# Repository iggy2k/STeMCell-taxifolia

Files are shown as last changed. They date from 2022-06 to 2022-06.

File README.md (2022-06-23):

# STeMCell-taxifolia
 STeMCell 1.0.0 but with STM32F401RCT6. Same functionality (almost), but for 5$ less per board.

Original STeMCell made by https://github.com/megamind4089

To use: https://megamind4089.github.io/STeMCell/

Changed nothing except the STM, positioning and silkscreens (still no on-board protections).

Haven't purchased yet, but it should work.

<p align="center">
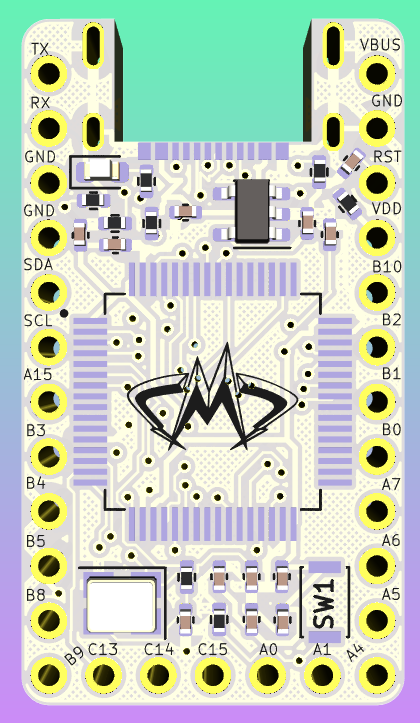
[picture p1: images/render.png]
  
</p>

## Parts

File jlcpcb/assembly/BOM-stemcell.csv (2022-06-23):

Comment | Designator | Footprint | LCSC
100n | C12,C4,C5,C6,C7,C8 | C_0402_1005Metric | C1525
10u | C1 | C_0402_1005Metric | C15525
20p | C10,C11 | C_0402_1005Metric | C1554
4.7u | C2,C3,C9 | C_0402_1005Metric | C23733
220 | R1 | R_0402_1005Metric | C25091
10k | R6,R7,R8 | R_0402_1005Metric | C25744
2k2 | R4 | R_0402_1005Metric | C25879
4.7k | R5 | R_0402_1005Metric | C25900
5k1 | R2,R3 | R_0402_1005Metric | C25905
USB C Connector | J1 | USB-C-C168688 | C2681552
HSE1 8Mhz 12pF | Y1 | Crystal_SMD_3225-4Pin_3.2x2.5mm | C2682775
Boot0 | SW1 | SW_SPST_CK_KXT3 | C319433
LED | D1 | LED_0603_1608Metric | C72041
STM32F401RCTx | U1 | QFP50P1200X1200X160-64N | C74524
XC6220B331MR | U2 | SOT-23-5 | C86534

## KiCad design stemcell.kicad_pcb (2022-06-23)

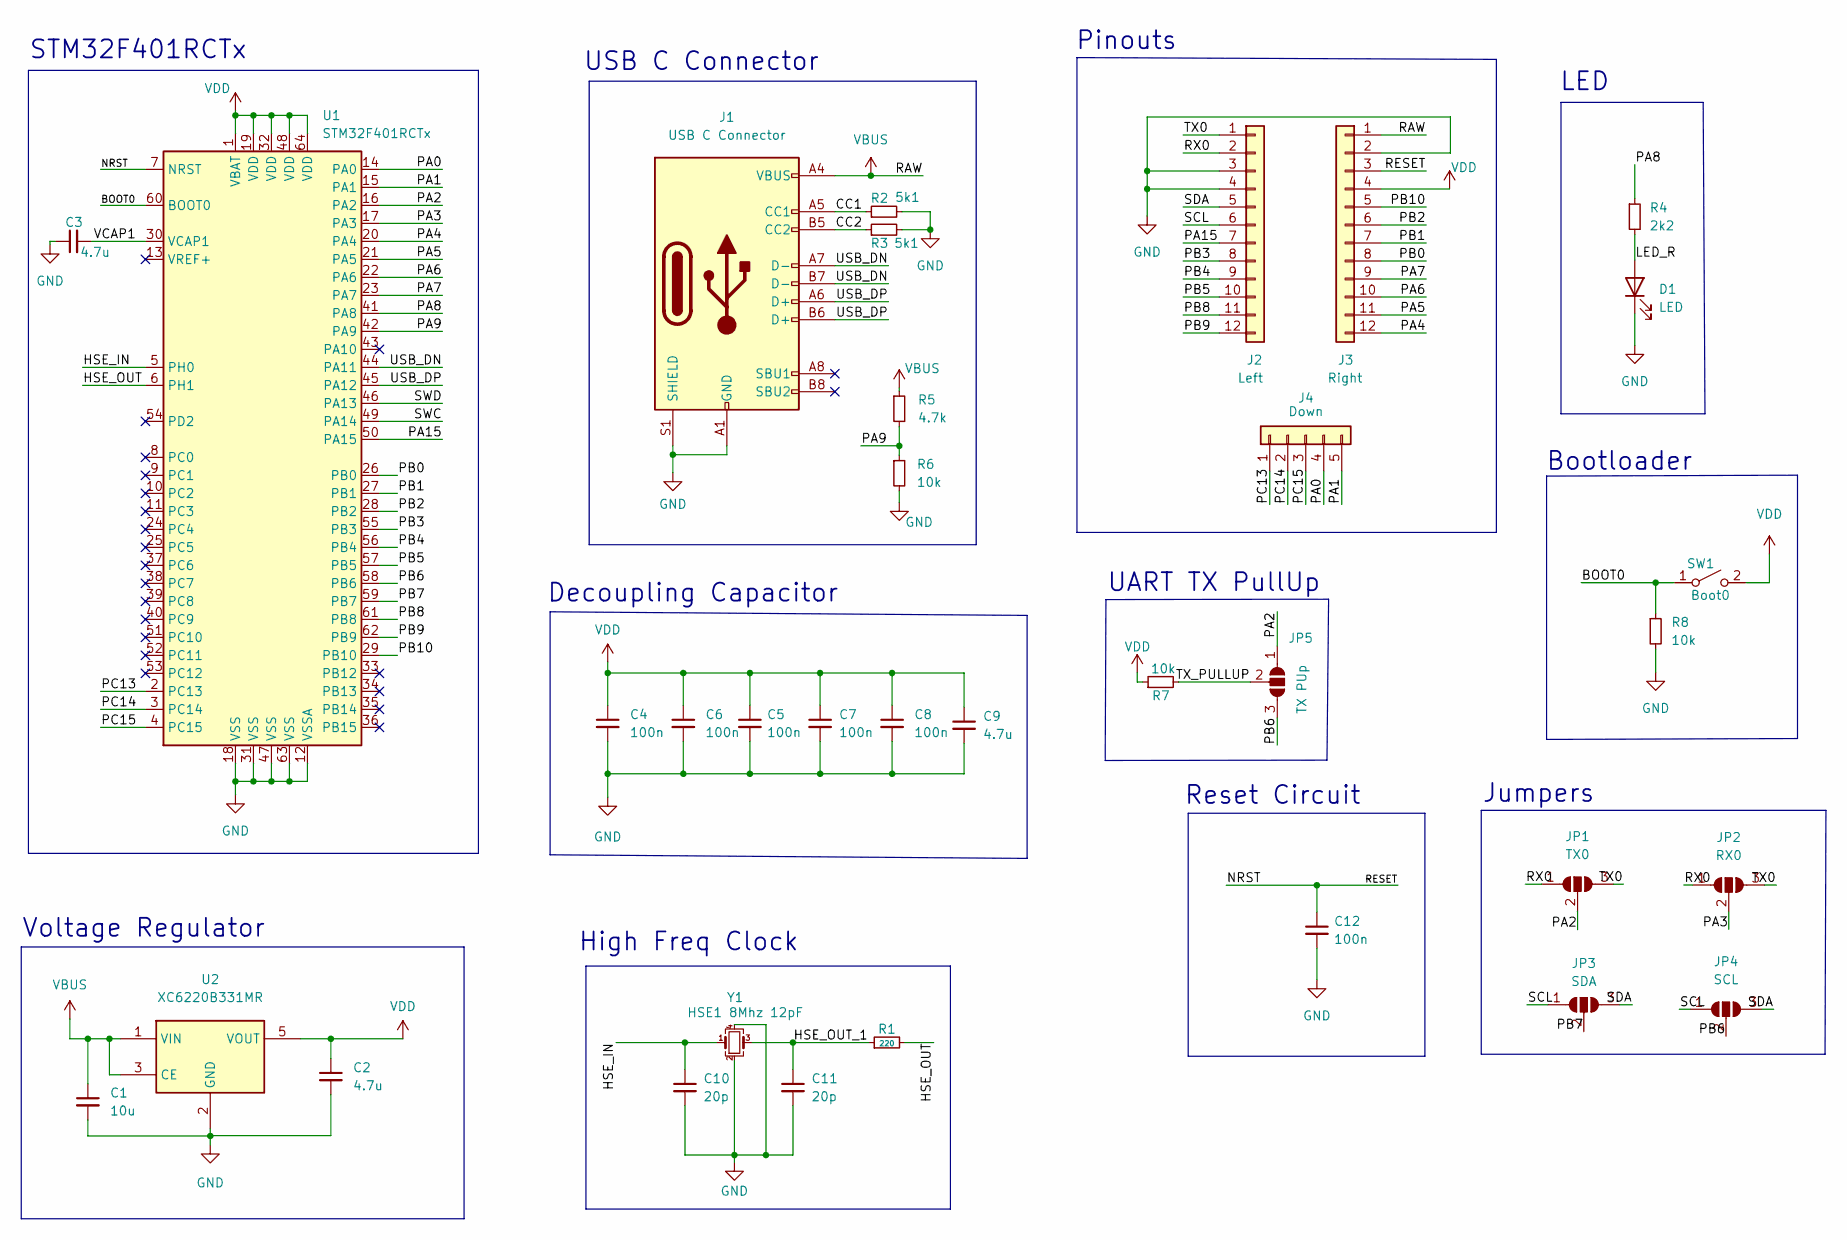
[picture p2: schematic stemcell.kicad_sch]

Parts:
C1: 10u; C_0402_1005Metric
C2, C3, C9: 4.7u; C_0402_1005Metric
C4, C5, C6, C7, C8, C12: 100n; C_0402_1005Metric
C10, C11: 20p; C_0402_1005Metric
D1: LED; LED_0603_1608Metric
J1: USB C Connector; USB-C-C168688
J2: Left; Pins_x12
J3: Right; Pins_x12
J4: Down; Pins_x05_Castellated
JP1: TX0; SOLDER_JUMPER_3
JP2: RX0; SOLDER_JUMPER_3
JP3: SDA; SOLDER_JUMPER_3
JP4: SCL; SOLDER_JUMPER_3
JP5: TX PUp; SOLDER_JUMPER_3
R1: 220; R_0402_1005Metric
R2, R3: 5k1; R_0402_1005Metric
R4: 2k2; R_0402_1005Metric
R5: 4.7k; R_0402_1005Metric
R6, R7, R8: 10k; R_0402_1005Metric
SW1: Boot0; SW_SPST_CK_KXT3
U1: STM32F401RCTx; QFP50P1200X1200X160-64N
U2: XC6220B331MR; SOT-23-5
Y1: HSE1 8Mhz 12pF; Crystal_SMD_3225-4Pin_3.2x2.5mm

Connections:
/BOOT0: R8.1, SW1.1 (A), U1.60 (BOOT0)
/CC1: J1.A5 (CC1), R2.1
/CC2: J1.B5 (CC2), R3.1
/HSE_IN: C10.1, U1.5 (PH0), Y1.1
/HSE_OUT: R1.2, U1.6 (PH1)
/HSE_OUT_1: C11.1, R1.1, Y1.3
/LED_R: D1.2 (A), R4.2
/NRST: C12.1, J3.3, U1.7 (NRST)
/PA0: J4.4, U1.14 (PA0)
/PA1: J4.5, U1.15 (PA1)
/PA2: JP1.2 (C), JP5.1 (A), U1.16 (PA2)
/PA3: JP2.2 (C), U1.17 (PA3)
/PA4: J3.12, U1.20 (PA4)
/PA5: J3.11, U1.21 (PA5)
/PA6: J3.10, U1.22 (PA6)
/PA7: J3.9, U1.23 (PA7)
/PA8: R4.1, U1.41 (PA8)
/PA9: R5.2, R6.1, U1.42 (PA9)
/PA15: J2.7, U1.50 (PA15)
/PB0: J3.8, U1.26 (PB0)
/PB1: J3.7, U1.27 (PB1)
/PB2: J3.6, U1.28 (PB2)
/PB3: J2.8, U1.55 (PB3)
/PB4: J2.9, U1.56 (PB4)
/PB5: J2.10, U1.57 (PB5)
/PB6: JP4.2 (C), JP5.3 (B), U1.58 (PB6)
/PB7: JP3.2 (C), U1.59 (PB7)
/PB8: J2.11, U1.61 (PB8)
/PB9: J2.12, U1.62 (PB9)
/PB10: J3.5, U1.29 (PB10)
/PC13: J4.1, U1.2 (PC13)
/PC14: J4.2, U1.3 (PC14)
/PC15: J4.3, U1.4 (PC15)
/RX0: J2.2, JP1.1 (A), JP2.1 (A)
/SCL: J2.6, JP3.1 (A), JP4.1 (A)
/SDA: J2.5, JP3.3 (B), JP4.3 (B)
/SWC: U1.49 (PA14)
/SWD: U1.46 (PA13)
/TX0: J2.1, JP1.3 (B), JP2.3 (B)
/TX_PULLUP: JP5.2 (C), R7.2
/USB_DN: J1.A7 (D-), J1.B7 (D-), U1.44 (PA11)
/USB_DP: J1.A6 (D+), J1.B6 (D+), U1.45 (PA12)
/VCAP1: C3.2, U1.30 (VCAP1)
GND: C1.2, C2.2, C3.1, C4.2, C5.2, C6.2, C7.2, C8.2, C9.2, C10.2, C11.2, C12.2, D1.1 (K), J1.A1 (GND), J1.A12 (GND), J1.B1 (GND), J1.B12 (GND), J1.S1 (SHIELD), J2.3, J2.4, J3.2, R2.2, R3.2, R6.2, R8.2, U1.12 (VSSA), U1.18 (VSS), U1.31 (VSS), U1.47 (VSS), U1.63 (VSS), U2.2 (GND), Y1.2, Y1.4
VBUS: C1.1, J1.A4 (VBUS), J1.A9 (VBUS), J1.B4 (VBUS), J1.B9 (VBUS), J3.1, R5.1, U2.1 (VIN), U2.3 (CE)
VDD: C2.1, C4.1, C5.1, C6.1, C7.1, C8.1, C9.1, J3.4, R7.1, SW1.2 (B), U1.1 (VBAT), U1.19 (VDD), U1.32 (VDD), U1.48 (VDD), U1.64 (VDD), U2.5 (VOUT)

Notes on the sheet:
Jumpers
Decoupling Capacitor
STM32F401RCTx
Reset Circuit
Voltage Regulator
LED
High Freq Clock
Bootloader
UART TX PullUp
USB C Connector
Pinouts

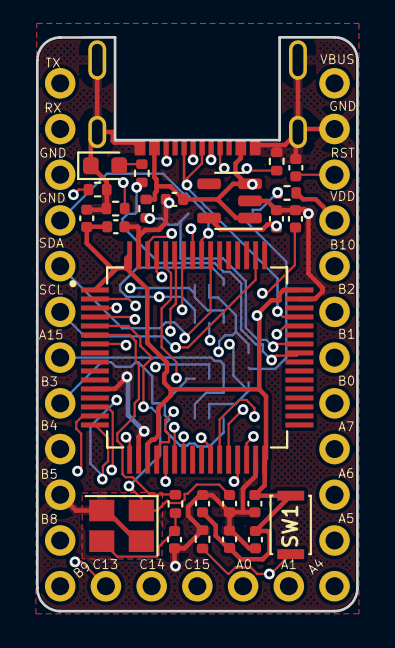
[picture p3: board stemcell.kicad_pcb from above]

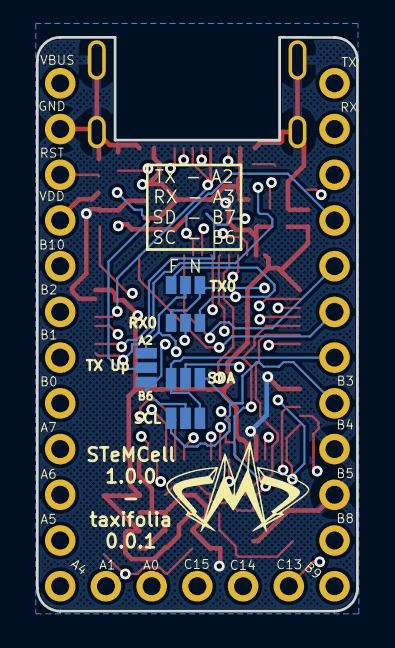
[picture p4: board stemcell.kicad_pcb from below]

Board: 4 copper layers, 17.8 x 31.9 mm, 34 parts (5 on the bottom side), 44 nets.

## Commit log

2022-06-23 Initial Commit
    Everything is ready for purchase/assembly.
    [BOM-stemcell.csv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]
2022-06-23 Move via out of the crystal zone.
    Regenerated the gerbers.
    [stemcell-CuBottom.gbr, stemcell-CuIn1.gbr, stemcell-CuIn2.gbr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]
2022-06-23 Moved capacitors out of the way of the pins
    Moved logo back to the back silkscreen.
    [POS-stemcell.csv, stemcell-CuBottom.gbr, stemcell-CuIn1.gbr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]
